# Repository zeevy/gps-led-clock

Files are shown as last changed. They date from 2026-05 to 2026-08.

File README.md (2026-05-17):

# GPS Clock with 32x8 LED Matrix Display

A sophisticated Arduino-based GPS clock that displays time on a 32x8 LED matrix with beautiful animations and effects. The clock automatically synchronizes with GPS time and includes a rain effect animation when GPS signal is lost.



## Features

- **GPS Time Synchronization**: Automatically syncs with GPS time (UTC) with timezone adjustment and signal quality monitoring
- **Dynamic Time Format**: Toggle between 12-hour (with AM/PM) or 24-hour display via power cycles
- **Animated Time Display**: Smooth vertical sliding animations when time digits change
- **Date Display**: Shows date with ordinal suffixes (1st, 2nd, 3rd, etc.) every 2 minutes 30 seconds
- **GPS Location Display**: Shows latitude, longitude, and altitude in feet (4 decimal places, ~11m accuracy) immediately after date display
- **Rain Effect Animation**: Beautiful rain animation when GPS signal is lost
- **Smart Signal Detection**: Uses GPS time age for reliable signal quality monitoring
- **Automatic Brightness Control**: Adjusts brightness based on time of day (night mode)
- **Fixed 32x8 Display**: Optimized for 4x MAX7219 LED matrix modules
- **Scrolling Text Messages**: Welcome and status messages with smooth scrolling
- **PM Indicator**: Visual indicator for PM time display
- **Blinking Colon**: Animated colon separator for time display

## Hardware Requirements

### Components

- **Arduino Nano** (or compatible Arduino board)
- **GPS Module** (NEO-6M or similar with NMEA output)
- **32x8 LED Matrix Display** (exactly 4x MAX7219 modules, 8x8 each)
- **Breadboard and jumper wires**
- **5V Power supply** (or USB power)

**Important**: This project is specifically designed for a **32x8 LED matrix** using **4x MAX7219 modules**. Other matrix sizes or configurations are not supported without code modifications.

**Note**: The matrix configuration is fixed and optimized for this specific setup. Changing the matrix size would require significant code modifications to the display logic, positioning calculations, and text scrolling functions.

### Pin Connections

| Component | Arduino Pin | Description |
|---|---|---|
| **GPS TX** | RX0 (Digital Pin 0)| GPS data output |
| **GPS VCC** | 5V | Power supply |
| **GPS GND** | GND | Ground |
| **LED Matrix DIN**  | Pin 11 (MOSI) | Data input |
| **LED Matrix CLK**  | Pin 13 (SCK) | Clock signal |
| **LED Matrix CS** | Pin 10 (SS) | Chip select |
| **LED Matrix VCC**  | 5V | Power supply |
| **LED Matrix GND**  | GND | Ground |



https://github.com/user-attachments/assets/0466696c-467c-4d51-b680-a392c1aeb819

## Software Requirements

- **PlatformIO** (recommended) or Arduino IDE
- **Arduino AVR Boards** package
- Required libraries (automatically installed with PlatformIO):
  - TinyGPSPlus
  - Adafruit GFX Library
  - Max72xxPanel
  - RTClib
  - TickTwo

## Installation & Setup

### Using PlatformIO (Recommended)

**Clone the repository**:

```bash
git clone https://github.com/zeevy/gps-led-clock.git
cd gps-led-clock
```

**Open in PlatformIO**:

```bash
pio project init
```

**Build and upload**:

```bash
pio run -t upload
```

> **Note:** Disconnect the GPS TX pin from Arduino RX0 during flashing/uploading.

## Configuration

### Time Format Configuration

The time format can be toggled dynamically using power cycle detection:

**Power Cycle Toggle:**

- **5 power cycles** during **startup sequence** toggles between formats
- Power cycles must occur between the random pixel animation and welcome message
- **12-hour format** is the default
- Format is stored in EEPROM and persists across reboots
- Format confirmation is shown when toggled

**12-Hour Format:**

- Displays time as 1:00 PM to 12:59 AM
- Shows PM indicator (bottom-right pixel) for PM times
- Example: "2:35." with PM indicator

**24-Hour Format:**

- Displays time as 00:00 to 23:59
- No AM/PM indicator
- Example: "14:35" (no indicator)

**How to Toggle:**

1. Power on the device
2. During the startup animation (between random pixel lighting and welcome message), power off the device and power it back on, repeating this 5 times
3. Wait for the welcome message to complete
4. If toggled, display will show the new format confirmation ("24H FORMAT" or "12H FORMAT")
5. New format persists across reboots

### Timezone Adjustment

To change the timezone, modify the timezone offset in `src/config.h`:

```cpp
// Current: IST (UTC+5:30)
#define TIMEZONE_OFFSET_DAYS    0
#define TIMEZONE_OFFSET_HOURS   5
#define TIMEZONE_OFFSET_MINUTES 30
#define TIMEZONE_OFFSET_SECONDS 0
```

### LED Matrix Configuration

This project is designed specifically for a **32x8 LED matrix** using **4x MAX7219 modules**. The matrix size and configuration are fixed and cannot be changed without code modifications.

**Matrix Specifications:**

- **Display Size**: 32x8 pixels
- **Modules**: 4x MAX7219 (8x8 each)
- **Arrangement**: Horizontal (4 modules side by side)
- **Orientation**: Standard left-to-right

### Display Settings

Modify these constants in `src/config.h`:

```cpp
// Brightness Settings (Adjustable)
#define LED_BRIGHTNESS_HIGH         10    // High brightness (0-15)
#define LED_BRIGHTNESS_LOW          5     // Low brightness (0-15)

// Timing Settings (Adjustable)
#define TIME_UPDATE_INTERVAL_MS     500  // GPS update interval
#define DATE_DISPLAY_INTERVAL_MS    (2 * 60 * 1000UL + 30 * 1000UL) // Date display interval
```

## Usage

### First Time Setup

1. **Power on** the device
2. **Wait for GPS signal** - Rain effect shows until GPS signal is acquired, every `DATE_DISPLAY_INTERVAL_MS` "Waiting for GPS signal..." will be shown, if GPS fix is not yet acquired
3. **Time will appear** once GPS signal is acquired

### Normal Operation

- **Time Display**: Shows current time in configurable format (12-hour or 24-hour) with blinking colon
- **Date Display**: Automatically shows date every 2 minutes 30 seconds
- **GPS Location**: Shows latitude, longitude, and altitude in feet (4 decimal places) after date display
- **PM Indicator**: Bottom-right pixel indicates PM time (12-hour format only)
- **Night Mode**: Automatically dims display from 9 PM to 6 AM
- **Rain Effect**: Activates when GPS signal is lost

### Serial Monitor

Connect to the serial monitor (115200 baud) to see:

- GPS data during signal acquisition
- Timestamp updates
- Status messages

## Customization

### Adding Custom Messages

Modify the welcome message in `src/config.h`:

```cpp
const char* WELCOME_MESSAGE = "Your Custom Message";
```

### Rain Effect Settings

Adjust rain effect parameters in `src/RainEffect.h`:

```cpp
static const int MAX_RAINDROPS = 12;           // Number of simultaneous drops
static const int RAIN_SPAWN_INTERVAL_MS = 200; // Spawn rate
static const int RAIN_FALL_SPEED_MIN_MS = 50;  // Minimum fall speed
static const int RAIN_FALL_SPEED_MAX_MS = 100; // Maximum fall speed
```

## Contributing

Contributions are welcome! Please feel free to submit a Pull Request. For major changes, please open an issue first to discuss what you would like to change.

### Development Guidelines

1. **Code Style**: Follow Arduino C++ conventions
2. **Documentation**: Add comprehensive comments and docstrings
3. **Testing**: Test on actual hardware before submitting
4. **Commits**: Use clear, descriptive commit messages

## Support

If you encounter any issues or have questions:

1. Search existing [Issues](https://github.com/zeevy/gps-led-clock/issues)
2. Create a new issue with detailed information
3. Include hardware setup and error messages

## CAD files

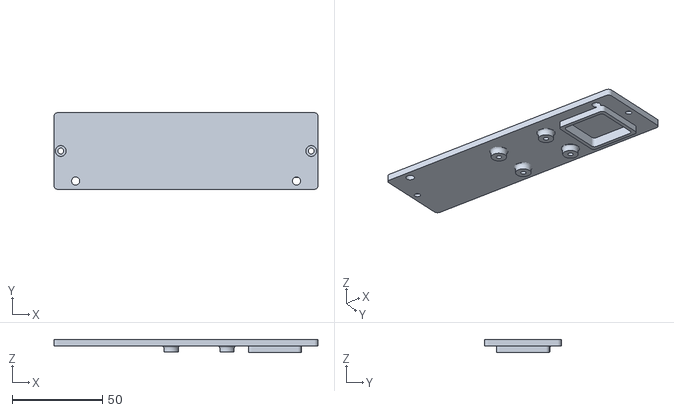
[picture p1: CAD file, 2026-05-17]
assets/back_panel.stl
146.5 x 42.5 x 6.95

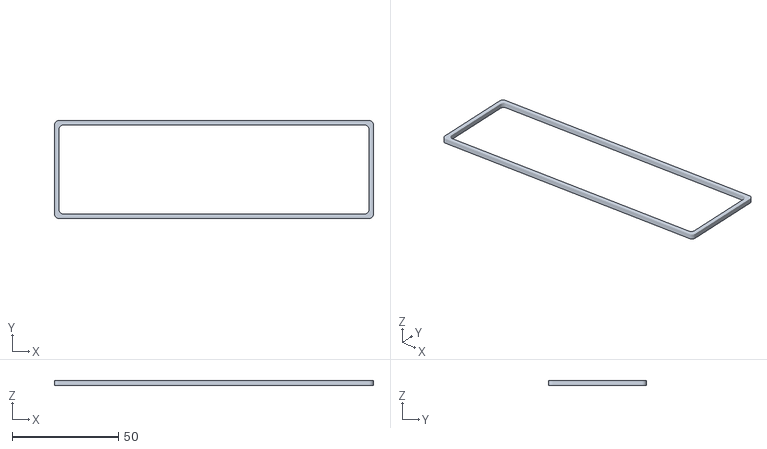
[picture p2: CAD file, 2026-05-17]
assets/ring.stl
150.0 x 46.0 x 2.40

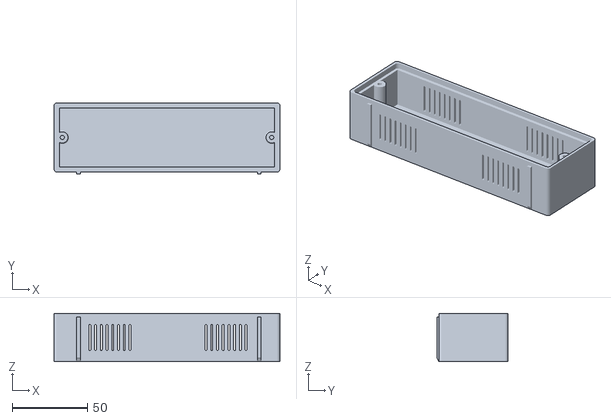
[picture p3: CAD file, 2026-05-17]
assets/case.stl
150.0 x 47.5 x 32.0

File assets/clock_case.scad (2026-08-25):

/*
 * Wall Clock Case for LED Matrix Display
 *
 * A 3D printable case designed for a 4x MAX7219 LED matrix display
 * with integrated GPS module mounting and ventilation system.
 *
 * Features:
 * - Customizable dimensions for different LED matrix sizes
 * - Integrated ventilation system for heat dissipation (optional cross-flow)
 * - GPS module mounting (Neo-6M compatible)
 * - M3 screw mounting system
 * - Rounded corners
 * - Modular design for easy customization
 *
 * Author: zeevy
 * License: MIT
 * Version: 1.1
 *
 * Dependencies:
 * - OpenSCAD 2019.05 or later
 *
 * Usage:
 * - Toggle the render flags in the Assembly section to choose what to export.
 * - Adjust parameters in the Configuration section as needed.
 * - Use $preview = true for fast preview, false for final render.
 */

// ============================================================================
// CONFIGURATION PARAMETERS
// ============================================================================

// Rendering quality
$fn = $preview ? 30 : 96;

// Render epsilon. Keeps boolean cuts from leaving zero-thickness faces.
// Tuned separately from physical assembly clearance (see back_panel_fit_tolerance).
eps = 0.05;

// Material and manufacturing parameters
wall_thickness        = 3.5;    // Thickness of case walls
screen_thickness      = 0.64;   // Thickness of screen/display area

// LED Matrix Display dimensions (MAX7219 4x configuration)
// Module is 128 x 33 x 15 mm (L x W x H) per the Handson Technology DSP-1172
// datasheet. Each dimension below is the module size plus a print clearance;
// the base numbers must stay equal to the datasheet, not to the 32 mm the
// matrix area alone measures, or the pocket ends up a press fit.
led_matrix_clearance_xy = 1.0;   // Clearance added to length and width
led_matrix_clearance_z  = 0.5;   // Clearance added to height
led_matrix_length     = 128 + led_matrix_clearance_xy;  // Module length + clearance
led_matrix_width      = 33  + led_matrix_clearance_xy;  // Module width + clearance
led_matrix_height     = 15  + led_matrix_clearance_z;   // Module height + clearance

// Main case dimensions
case_length           = 150;    // Total length of the case
case_width            = 46;     // Total width of the case
case_height           = 32;     // Total height of the case
case_bottom_thickness = 5;      // Thickness of bottom panel that holds the LED matrix
case_corner_radius    = 2;      // Corner radius for case and panel geometry

// Back panel fit. Total radial clearance between panel and its recess in the case.
back_panel_fit_tolerance = 0.3;

// Ventilation
ventilation_hole_diameter   = 1.26;
ventilation_slot_length     = 16;
ventilation_hole_spacing    = 3.8;
ventilation_hole_count      = 8;
ventilation_enable_back_wall = true;  // Mirror vents to opposite long wall for cross-flow

// GPS antenna (Neo-6M is square ~25mm)
gps_antenna_size            = 25.25;
gps_module_cutout_inset_x   = 40;   // Distance from case end (back panel antenna cutout)
gps_module_bracket_inset_x  = 42;   // Distance from case end (back panel bracket)
gps_post_origin_x           = 96;   // X offset for Neo-6M PCB mounting posts (back panel frame)
gps_post_spacing_x          = 31;   // PCB hole spacing in X (Neo-6M board)
gps_post_spacing_y          = 20.6; // PCB hole spacing in Y (Neo-6M board)

// Hardware
m3_screw_tap_hole_diameter         = 2.8;   // Self-tap hole in mounting feet
m3_screw_shaft_clearance_diameter  = 3.25;  // Through-hole in back panel
m3_screw_distance_from_edge        = 5.5;   // Distance from case edge to mounting feet/holes
m3_screw_head_recess_diameter      = 6;     // Counterbore diameter for screw head
// Counterbore depth into the back panel. With 2.0mm depth in a 3.5mm panel, a
// standard 3mm cap head will sit ~1mm proud. Increase toward ~3.0mm if you use
// flat/countersunk M3 screws (panel still needs material below the recess).
m3_screw_head_recess_depth         = 2;

// Cable management
cable_pass_through_diameter        = 4.5;
cable_pass_through_inset_x         = 12;  // Distance from each end of the back panel
cable_pass_through_y               = 4.6;

// Mounting bars on the underside of the case
foot_bar_inset_x                   = 15;

// Display ring
display_ring_thickness             = 2.4;  // Z thickness of the ring
display_ring_border                = 4.2;  // XY width of the ring border

// Assembly render toggles
render_case        = false;
render_back_panel  = false;
render_display_ring = true;

// ============================================================================
// SANITY ASSERTIONS
// ============================================================================

assert(case_length > led_matrix_length + 2 * wall_thickness,
       "case_length must accommodate led_matrix_length plus side walls");
assert(case_width > led_matrix_width + 2 * wall_thickness,
       "case_width must accommodate led_matrix_width plus side walls");
assert(case_height > led_matrix_height + case_bottom_thickness + wall_thickness,
       "case_height must accommodate led_matrix_height plus floor and back panel");
assert(m3_screw_head_recess_depth < wall_thickness,
       "m3_screw_head_recess_depth must leave material below; reduce depth or thicken wall");

// ============================================================================
// MAIN ASSEMBLY
// ============================================================================

color("lightgray") {
  if (render_case) {
    led_case();
  }

  if (render_back_panel) {
    translate([
      wall_thickness/2,
      wall_thickness/2,
      case_height - wall_thickness + display_ring_thickness/2
    ]) led_case_back_panel(include_holes = true, gap = 0);
  }

  if (render_display_ring) {
    translate([0, 0, display_ring_thickness/2]) display_ring();
  }
}

// ============================================================================
// CORE MODULES
// ============================================================================

/**
 * Main LED case. Primary housing for the LED matrix display with integrated
 * ventilation, mounting points, and cable management.
 */
module led_case() {
  union() {
    difference() {
      // Outer case shell
      rounded_box(case_length, case_width, case_height, case_corner_radius);

      // Interior cavity
      translate([wall_thickness, wall_thickness, case_bottom_thickness]) {
        cube([case_length - wall_thickness * 2,
              case_width - wall_thickness * 2,
              case_height + wall_thickness]);
      }

      // LED matrix cutout
      translate([(case_length - led_matrix_length)/2,
                 (case_width - led_matrix_width)/2,
                 screen_thickness]) {
        led_matrix_cutout();
      }

      // Back panel mounting recess. Subtract ONLY the plate shape so the GPS
      // bracket and mounting posts (added by led_case_back_panel) do not also
      // carve features into the case body.
      translate([wall_thickness/2,
                 wall_thickness/2,
                 case_height - wall_thickness + eps]) {
        back_panel_plate(include_holes = false, gap = back_panel_fit_tolerance);
      }

      // Ventilation on the y=0 long wall
      create_ventilation_slots(start_x = 20);
      create_ventilation_slots(
        start_x = case_length - (20 + ventilation_hole_spacing * ventilation_hole_count + ventilation_hole_diameter * 2)
      );

      // Optional mirrored vents on the y=case_width wall for cross-flow
      if (ventilation_enable_back_wall) {
        translate([0, case_width, 0]) mirror([0, 1, 0]) {
          create_ventilation_slots(start_x = 20);
          create_ventilation_slots(
            start_x = case_length - (20 + ventilation_hole_spacing * ventilation_hole_count + ventilation_hole_diameter * 2)
          );
        }
      }
    }

    create_mounting_feet();
    create_bottom_feet();
  }
}

/**
 * Back panel assembly: plate plus GPS bracket plus GPS PCB mounting posts.
 * @param include_holes Whether to include screw, GPS, and cable cutouts.
 * @param gap Additional clearance applied to the plate footprint.
 */
module led_case_back_panel(include_holes = true, gap = 0) {
  union() {
    back_panel_plate(include_holes, gap);
    create_gps_mounting_bracket();
    translate([gps_post_origin_x, case_width/4, eps * 2]) {
      rotate([0, 180, 0]) neo_6m_mounting_posts();
    }
  }
}

/**
 * Back panel plate only (rounded box plus optional cutouts). Used standalone
 * for the printed plate and as the recess shape carved into the case body.
 */
module back_panel_plate(include_holes = true, gap = 0) {
  difference() {
    rounded_box(
      case_length - wall_thickness + gap,
      case_width  - wall_thickness + gap,
      wall_thickness,
      case_corner_radius
    );
    if (include_holes) {
      create_m3_mounting_holes();
      create_gps_module_cutout();
      create_cable_pass_throughs();
    }
  }
}
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

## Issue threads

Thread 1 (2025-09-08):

Replace single fixed EEPROM addresses with a slot-based wear-leveling system.

zeevy, 2025-09-08:
The Arduino project currently stores user settings (like 12h/24h mode) and counters (like power-cycle count) in EEPROM at fixed addresses.
Since EEPROM cells have a limited write endurance (~100k cycles per cell), repeatedly writing to the same address can eventually wear it out.

We want to extend the lifetime by implementing a simple wear-leveling mechanism: instead of always writing to the same EEPROM address, distribute writes across a predefined set of slots (e.g., 16).

Have a dedicated file/class for this

Replace single fixed EEPROM addresses with a slot-based wear-leveling system.
Add logic to rotate writes across slots and scan for the latest value at startup.
Keep defaults and validation in place so the system is robust.

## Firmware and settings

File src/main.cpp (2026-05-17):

/**
 * @file main.cpp
 * @brief GPS Clock with 4xMAX7219 LED Matrix Display
 * 
 * This Arduino project creates a GPS-synchronized clock that displays time on a 32x8 LED matrix.
 * The project is specifically designed for 4x MAX7219 modules arranged horizontally.
 * Features include:
 * - GPS time synchronization with timezone adjustment
 * - Animated time display with vertical slide transitions
 * - Date display with ordinal suffixes
 * - Rain effect animation when GPS signal is lost
 * - Automatic brightness adjustment for day/night
 * - Scrolling text messages
 * - Fixed 32x8 matrix display (4x MAX7219 modules)
 * 
 * @author zeevy
 * @version 1.0.0
 * @date 2025-09-06
 * @license MIT
 */

#include <config.h>
#include "RainEffect.h"
#include "GpsStabilityFilter.h"

// ============================================================================
// CONSTANTS AND CONFIGURATION
// ============================================================================

// Space between characters in pixels for text scrolling
const int CHAR_SPACING = 1;

// Total character width including spacing for text scrolling
const int CHAR_WIDTH = 5 + CHAR_SPACING;

// ============================================================================
// GLOBAL VARIABLES
// ============================================================================

// ----------------------------------------------------------------------------
// GPS AND SIGNAL TRACKING
// ----------------------------------------------------------------------------
TinyGPSPlus gpsModule;                    // GPS module interface
bool wasShowingRainEffect = false;        // Track previous rain effect state for efficient screen clearing
GpsStabilityFilter gpsFilter(gpsModule);  // GPS coordinates stability filter

// ----------------------------------------------------------------------------
// TIME AND DATE MANAGEMENT
// ----------------------------------------------------------------------------
DateTime currentDateTime;                 // Current date and time from GPS
TimeDigits currentTimeDigits;             // Current time digits for display
TimeDigits previousTimeDigits;            // Previous time digits for animation comparison
bool is24Hour = false;                    // Time format cache (read once in setup for performance)
bool toggleBlinker = false;               // Controls colon blinking state in time display

// ----------------------------------------------------------------------------
// DISPLAY AND ANIMATION
// ----------------------------------------------------------------------------
Max72xxPanel ledMatrix = Max72xxPanel(MATRIX_CS_PIN, MATRIX_TOTAL_MODULES_X, MATRIX_TOTAL_MODULES_Y);
RainEffect rainEffect(ledMatrix);         // Rain effect animation object
char textScrollBuffer[TEXT_BUFFER_SIZE];  // Buffer for scrolling text display

// ----------------------------------------------------------------------------
// TIMERS
// ----------------------------------------------------------------------------
TickTwo gpsTimeUpdateTicker(updateGpsTime, TIME_UPDATE_INTERVAL_MS);  // Timer for GPS time updates
TickTwo dateDisplayTicker(displayDate, DATE_DISPLAY_INTERVAL_MS);     // Timer for date display

/**
 * @brief Arduino setup function - initializes the GPS clock system
 * 
 * This function performs the following initialization steps:
 * 1. Initializes serial communication for debugging
 * 2. Configures the LED matrix display
 * 3. Runs a startup animation
 * 4. Displays welcome message
 * 5. Starts the GPS time update and date display timers
 * 
 * @note This function runs once when the Arduino starts up
 */
void setup() {
  Serial.begin(115200);
  while (!Serial) delay(100);

  // Initialize LED matrix with low brightness
  ledMatrix.setIntensity(LED_BRIGHTNESS_LOW);
  ledMatrix.fillScreen(LOW);
  ledMatrix.write();
  configureLedMatrix();

  // Read time format from EEPROM once
  uint8_t format = EEPROM.read(EEPROM_TIME_FORMAT_ADDR);
  is24Hour = (format == 1);

  // Detect power cycles for time format switching
  checkPowerCycles();

  // Fun startup animation: randomly light up LEDs (increased delay for power cycle detection)
  randomSeed(analogRead(A0));
  for (int i = 0; i < ledMatrix.width() * ledMatrix.height(); i++) {
    ledMatrix.drawPixel(random(ledMatrix.width()), random(ledMatrix.height()), HIGH);
    ledMatrix.write();
    delay(5);
  }

  // Display welcome message and start timers
  scrollTextHorizontally(WELCOME_MESSAGE);

  // Reset power cycle counter after welcome message
  EEPROM.put(EEPROM_POWER_CYCLE_ADDR, (unsigned long)0);

  gpsTimeUpdateTicker.start();
  dateDisplayTicker.start();
}

void loop() {
  while (Serial.available()){
    char receivedChar = Serial.read();
    gpsModule.encode(receivedChar);
  }

  if (validGpsDateTime()) {
    // GPS signal good - clear screen if transitioning from rain effect
    // This prevents rain drops from being visible with time display
    if (wasShowingRainEffect) {
      ledMatrix.fillScreen(LOW);
      rainEffect.reset();
      previousTimeDigits = TimeDigits();
      wasShowingRainEffect = false;
    }

    gpsTimeUpdateTicker.update();
    dateDisplayTicker.update();
  }else{
    // GPS signal lost - show rain effect
    if (!rainEffect.isInitialized()) rainEffect.initialize();
    rainEffect.update();
    rainEffect.render();
    wasShowingRainEffect = true;
  }
}

/**
 * @brief Checks if the GPS date and time are valid and recent.
 * 
 * This function validates that the GPS location, date, and time are all valid,
 * and that the GPS data is not stale (i.e., received within the configured timeout).
 * 
 * @return true if GPS location, date, and time are valid and recent; false otherwise.
 */
bool validGpsDateTime() {
  return gpsModule.location.isValid() &&
         gpsModule.location.age() < GPS_SIGNAL_TIMEOUT_MS &&
         gpsModule.date.isValid() &&
         gpsModule.time.isValid();
}

/**
 * @brief Updates GPS time and displays it on the LED matrix
 * 
 * This function is called periodically by the GPS time update timer. It:
 * 1. Validates GPS data availability
 * 2. Converts GPS time to local timezone (configurable)
 * 3. Extracts individual time digits
 * 4. Animates digit changes with vertical slide effect
 * 5. Displays PM indicator and blinking colon
 * 
 * @note This function is called every TIME_UPDATE_INTERVAL_MS milliseconds
 * @note Timezone offset is configurable in config.h via TIMEZONE_OFFSET_* defines
 */
void updateGpsTime() {
  if (gpsModule.date.isValid() && gpsModule.time.isValid()) {
    // Create DateTime object from GPS data with timezone adjustment
    // Timezone offset is configured in config.h
    currentDateTime = DateTime(
      gpsModule.date.year(), gpsModule.date.month(), gpsModule.date.day(),
      gpsModule.time.hour(), gpsModule.time.minute(), gpsModule.time.second()
    ) + TimeSpan(TIMEZONE_OFFSET_DAYS, TIMEZONE_OFFSET_HOURS, TIMEZONE_OFFSET_MINUTES, TIMEZONE_OFFSET_SECONDS);

    // Extract individual digits for display
    extractTimeDigits(currentTimeDigits);

    // Animate digit changes with vertical slide effect
    if (currentTimeDigits.minOnes != previousTimeDigits.minOnes) {
      animateVerticalSlide(previousTimeDigits.minOnes, currentTimeDigits.minOnes, 25);
    }

    if (currentTimeDigits.minTens != previousTimeDigits.minTens) {
      animateVerticalSlide(previousTimeDigits.minTens, currentTimeDigits.minTens, 18);
    }

    if (currentTimeDigits.hourOnes != previousTimeDigits.hourOnes) {
      animateVerticalSlide(previousTimeDigits.hourOnes, currentTimeDigits.hourOnes, 7);
    }

    if (currentTimeDigits.hourTens != previousTimeDigits.hourTens) {
      animateVerticalSlide(previousTimeDigits.hourTens, currentTimeDigits.hourTens, 1);
    }

    // Display PM indicator in bottom-right corner (only in 12-hour format)
    if (!is24Hour) {
      ledMatrix.drawPixel(ledMatrix.width() - 1, ledMatrix.height() - 1, currentDateTime.isPM());
    }

    // Toggle the colon blinker for time separator
    for (byte i = 0; i < sizeof(COLON_BLINK_POSITIONS) / sizeof(COLON_BLINK_POSITIONS[0]); i++) {
      ledMatrix.drawPixel(COLON_BLINK_POSITIONS[i][0], COLON_BLINK_POSITIONS[i][1], toggleBlinker);
    }

    ledMatrix.write();

    // Print timestamp to serial when seconds change (debug only)
    #if ENABLE_SERIAL_DEBUG
    if (currentTimeDigits.secOnes != previousTimeDigits.secOnes) {
      Serial.println(currentDateTime.timestamp(DateTime::TIMESTAMP_FULL));
    }
    #endif

    // Update previous digits for next comparison
    extractTimeDigits(previousTimeDigits);
    toggleBlinker = !toggleBlinker;
  }
}

/**
 * @brief Configures LED matrix module positions and rotations
 * 
 * This function sets up the 4x MAX7219 LED matrix modules for a 32x8 display.
 * The matrix is configured in a standard horizontal arrangement:
 * - 4 modules arranged horizontally (8x8 each)
 * - Total display size: 32x8 pixels
 * - Standard left-to-right positioning
 * - No rotation applied (0 degrees)
 * 
 * @note This function is designed specifically for 4x MAX7219 modules
 * @note Matrix size is fixed to 32x8 pixels
 */
void configureLedMatrix() {
  int totalModules = MATRIX_TOTAL_MODULES_X * MATRIX_TOTAL_MODULES_Y;

  for (int moduleIndex = 0; moduleIndex < totalModules; moduleIndex++) {
    // Calculate base position for this module
    byte xPosition = moduleIndex % MATRIX_TOTAL_MODULES_X;
    byte yPosition = moduleIndex / MATRIX_TOTAL_MODULES_X;
    byte rotationAngle = 1; // Default rotation (0 degrees)

    ledMatrix.setPosition(moduleIndex, xPosition, yPosition);
    ledMatrix.setRotation(moduleIndex, rotationAngle);
  }
}

/**
 * @brief Scrolls text horizontally across the LED matrix display
 * 
 * This function creates a smooth horizontal scrolling effect for text messages.
 * The text scrolls from right to left across the display. If the text is shorter
 * than the display width, it will still scroll to ensure visibility.
 * 
 * @param message The text message to scroll (null-terminated string)
 * 
 * @note The function adds a space at the end of the message for better readability
 * @note Scroll speed is controlled by the delay(30) - adjust for different speeds
 * @note This function resets the previousTimeDigits to prevent animation conflicts
 * 
 * @example
 * scrollTextHorizontally("Hello World"); // Scrolls "Hello World " across display
 */
void scrollTextHorizontally(const char* message) {  
  // Print message to serial for debugging
  #if ENABLE_SERIAL_DEBUG
  Serial.println(message);
  #endif

  // Prepare text buffer with trailing space for better readability
  snprintf(textScrollBuffer, sizeof(textScrollBuffer), "%s ", message);

  // Calculate total text width in pixels
  int totalTextWidth = strlen(textScrollBuffer) * CHAR_WIDTH;
  
  // Ensure minimum scroll distance is at least the display width
  if (totalTextWidth < ledMatrix.width()) {
    totalTextWidth = ledMatrix.width();
  }

  // Scroll text from right edge to left edge
  for (int xPosition = ledMatrix.width(); xPosition >= -totalTextWidth; xPosition--) {
    // Drain serial buffer to prevent GPS data loss during long scrolls
    while (Serial.available()) {
      gpsModule.encode(Serial.read());
    }

    // Clear display and set cursor position
    ledMatrix.fillScreen(LOW);
    ledMatrix.setCursor(xPosition, 0);
    ledMatrix.print(textScrollBuffer);
    ledMatrix.write();
    delay(35); // Control scroll speed (35ms per frame)
  }

  // Reset previous time digits to prevent animation conflicts
  previousTimeDigits = TimeDigits();
}

/**
 * @brief Displays the current date with ordinal suffixes and adjusts brightness
 * 
 * This function is called periodically by the date display timer. It:
 * 1. Checks if GPS time is acquired, shows waiting message if not
 * 2. Formats the date with weekday, day with ordinal suffix, month, and year
 * 3. Scrolls the formatted date across the display
 * 4. Adjusts LED brightness based on time of day (night mode)
 * 
 * @note Called every DATE_DISPLAY_INTERVAL_MS milliseconds
 * @note Night mode: low brightness from 9PM to 6AM, high brightness otherwise
 * @note Date format: "Mon 1st Jan 2024" (example)
 * 
 * @example
 * // If current date is Monday, January 1st, 2024
 * // Display will show: "Mon 1st Jan 2024"
 */
void displayDate() {
  // Show waiting message if GPS time is not valid
  if (!gpsModule.time.isValid()) {
    scrollTextHorizontally(WAITING_FOR_GPS);
    return;
  }

  // Bounds checking for array access using Arduino constrain function
  int dayOfWeek = constrain(currentDateTime.dayOfTheWeek(), 0, 6);
  int month = constrain(currentDateTime.month(), 1, 12);

  // Format date string with ordinal suffix
  // Format: "Day OrdinalSuffix Month Year" (e.g., "Mon 1st Jan 2024")
  int day = currentDateTime.day();
  const char* ordinalSuffix = getOrdinalSuffix(day);

  snprintf(
    textScrollBuffer, sizeof(textScrollBuffer),
    "%s %d%s %s %d",
    WEEKDAY_NAMES[dayOfWeek],
    day,
    ordinalSuffix,
    MONTH_NAMES[month - 1],
    currentDateTime.year()
  );

  // Display the formatted date
  scrollTextHorizontally(textScrollBuffer);
  displayGpsLocation();

  // Adjust brightness based on time of day (night mode)
  if (currentDateTime.hour() >= 21 || currentDateTime.hour() <= 6) {
    // Night hours: 9PM to 6AM - use low brightness
    ledMatrix.setIntensity(LED_BRIGHTNESS_LOW);
  } else {
    // Day hours: 6AM to 9PM - use high brightness
    ledMatrix.setIntensity(LED_BRIGHTNESS_HIGH);
  }
}

/**
 * @brief Returns the appropriate ordinal suffix for a given number
 * 
 * This function determines the correct ordinal suffix (st, nd, rd, th) for a number.
 * It handles special cases for numbers ending in 11, 12, 13 (which all use "th")
 * and regular cases for other numbers.
 * 
 * @param number The number to get the ordinal suffix for
 * @return Pointer to the ordinal suffix string ("st", "nd", "rd", or "th")
 * 
 * @note This is a helper function for date formatting
 * 
 * @example
 * getOrdinalSuffix(1)  // Returns "st" (1st)
 * getOrdinalSuffix(2)  // Returns "nd" (2nd)
 * getOrdinalSuffix(3)  // Returns "rd" (3rd)
 * getOrdinalSuffix(11) // Returns "th" (11th)
 * getOrdinalSuffix(21) // Returns "st" (21st)
 */
const char* getOrdinalSuffix(int number) {
  int lastTwoDigits = number % 100;
  int lastDigit = number % 10;

  // Special case: 11th, 12th, 13th all use "th"
  if (lastTwoDigits >= 11 && lastTwoDigits <= 13) {
    return "th";
  } else {
    // Regular cases based on last digit
    switch (lastDigit) {
      case 1: return "st";
      case 2: return "nd";
      case 3: return "rd";
      default: return "th";
    }
  }
}

/**
 * @brief Extracts individual digits from the current time for display
 * 
 * This function takes the current date/time and extracts individual digits
 * for hours, minutes, and seconds. It converts the numeric values to ASCII
 * characters for display on the LED matrix.
 * 
 * @param digits Reference to TimeDigits struct to store the extracted digits
 * 
 * @note Uses configurable time format (12-hour or 24-hour) based on TIME_FORMAT_* defines
 * @note All digits are converted to ASCII characters ('0' to '9')
 * 
 * @example
 * // 12-hour format: If current time is 2:35:47 PM
 * // digits.hourTens = '0', digits.hourOnes = '2'
 * // 24-hour format: If current time is 14:35:47
 * // digits.hourTens = '1', digits.hourOnes = '4'
 */
void extractTimeDigits(TimeDigits& digits) {
  // Get time components based on cached format
  int hour;
  if (is24Hour) {
    hour = currentDateTime.hour();
  } else {
    hour = currentDateTime.twelveHour();
  }

  int minute = currentDateTime.minute();
  int second = currentDateTime.second();

  // Extract and convert digits to ASCII characters
  digits.hourOnes = (hour % 10) + '0';
  digits.hourTens = (hour / 10) + '0';
  digits.minOnes = (minute % 10) + '0';
  digits.minTens = (minute / 10) + '0';
  digits.secOnes = (second % 10) + '0';
  digits.secTens = (second / 10) + '0';
}

/**
 * @brief Creates a vertical sliding animation when time digits change
 * 
 * This function creates a smooth vertical sliding effect when a time digit changes.
 * The old character slides down while the new character slides up from the top,
 * creating a visually appealing transition effect.
 * 
 * @param previousChar The character that was previously displayed
 * @param newChar The new character to display
 * @param xPosition The X coordinate where the animation occurs
 * 
 * @note Animation speed is controlled by delay(25) - adjust for different speeds
 * @note This function blocks execution during animation
 * 
 * @example
 * animateVerticalSlide('5', '6', 25); // Animate change from '5' to '6' at x=25
 */
void animateVerticalSlide(char previousChar, char newChar, int xPosition) {
  // Create sliding effect by moving both characters vertically
  for (uint8_t yPosition = 0; yPosition <= ledMatrix.height(); yPosition++) {
    // Draw new character sliding up from top
    ledMatrix.drawChar(xPosition, yPosition - ledMatrix.height(), newChar, HIGH, LOW, 1);
    // Draw previous character sliding down
    ledMatrix.drawChar(xPosition, yPosition, previousChar, HIGH, LOW, 1);
    ledMatrix.write();
    delay(25); // Control animation speed (25ms per frame)
  }
}

/**
 * @brief Displays GPS location information (latitude, longitude, altitude)
 * 
 * This function displays the current GPS coordinates
 * immediately after the date display. It shows:
 * - Latitude with "LAT:" prefix (4 decimal places, ~11m accuracy)
 * - Longitude with "LON:" prefix (4 decimal places, ~11m accuracy)
 * - Altitude with "ALT:" prefix and "ft" suffix (1 decimal place,
 * 
 * @note Only displays if GPS location data is valid
 * @note Each coordinate is displayed on a separate line with scrolling
 * @note GPS precision is fixed at 4 decimal places for optimal readability
 * @note All values are validated before display to prevent invalid data
 * @note Uses integer arithmetic to avoid sprintf floating-point issues on Arduino
 */
void displayGpsLocation() {
  if (!gpsModule.location.isValid()) return;

  // Update GPS stability filter with new readings
  gpsFilter.update();

  // Display latitude using filtered value for stability (4 decimal places = ~11m accuracy)
  float lat = gpsFilter.getFilteredLatitude();
  int latInt = (int)lat;
  int latFrac = (int)(fabs(lat - latInt) * GPS_COORD_PRECISION_MULTIPLIER);

  #if ENABLE_SERIAL_DEBUG
  // Debug output: show raw vs filtered values
  Serial.print("LAT - Raw: ");
  Serial.print(gpsModule.location.lat(), 6);
  Serial.print(", Filtered: ");
  Serial.print(lat, 6);
  Serial.print(", Readings: ");
  Serial.println(gpsFilter.getTotalReadings());
  #endif

  snprintf(textScrollBuffer, sizeof(textScrollBuffer), "%s%d.%04d", GPS_LAT_PREFIX, latInt, latFrac);
  scrollTextHorizontally(textScrollBuffer);

  // Display longitude using filtered value for stability (4 decimal places = ~11m accuracy)
  float lng = gpsFilter.getFilteredLongitude();
  int lngInt = (int)lng;
  int lngFrac = (int)(fabs(lng - lngInt) * GPS_COORD_PRECISION_MULTIPLIER);

  #if ENABLE_SERIAL_DEBUG
  // Debug output: show raw vs filtered values
  Serial.print("LON - Raw: ");
  Serial.print(gpsModule.location.lng(), 6);
  Serial.print(", Filtered: ");
  Serial.println(lng, 6);
  #endif

  snprintf(textScrollBuffer, sizeof(textScrollBuffer), "%s%d.%04d", GPS_LON_PREFIX, lngInt, lngFrac);
  scrollTextHorizontally(textScrollBuffer);

  // Display altitude using filtered value for stability if available
  if (gpsModule.altitude.isValid()) {
    // Use filtered altitude value and integer arithmetic since Arduino sprintf doesn't support floating-point
    double altFeet = gpsFilter.getFilteredAltitude();
    int altInt = (int)altFeet;
    int altFrac = (int)(fabs(altFeet - altInt) * GPS_ALT_PRECISION_MULTIPLIER);

    #if ENABLE_SERIAL_DEBUG
    // Debug output: show raw vs filtered altitude
    Serial.print("ALT - Raw: ");
    Serial.print(gpsModule.altitude.feet(), 2);
    Serial.print("ft, Filtered: ");
    Serial.print(altFeet, 2);
    Serial.println("ft");
    #endif

    snprintf(textScrollBuffer, sizeof(textScrollBuffer), "%s%d.%d%s", GPS_ALT_PREFIX, altInt, altFrac, GPS_ALT_SUFFIX);
    scrollTextHorizontally(textScrollBuffer);
  }
}

/**
 * @brief Detects power cycles and toggles time format if threshold is reached
 * 
 * This function detects power cycles during the startup sequence to toggle between 
 * 12-hour and 24-hour time formats. The detection uses EEPROM to store cycle count.
 * 
 * The system works by incrementing a counter on each power cycle during startup.
 * If the counter reaches the threshold (5), it toggles the time format and resets 
 * the counter. The counter is reset after the welcome message to prevent accidental 
 * toggles during normal operation.
 * 
 * @note Called in setup() to detect power cycles for format switching
 * @note Uses EEPROM to persist cycle data across reboots
 * @note Counter resets after welcome message
 */
void checkPowerCycles() {
  // Read cycle count from EEPROM
  unsigned long cycleCount = 0;
  EEPROM.get(EEPROM_POWER_CYCLE_ADDR, cycleCount);

  // Validate against uninitialized EEPROM (0xFFFFFFFF) or corrupt values
  if (cycleCount > POWER_CYCLE_THRESHOLD * 2) {
    cycleCount = 0;
  }

  // Increment cycle count
  cycleCount++;
  EEPROM.put(EEPROM_POWER_CYCLE_ADDR, cycleCount);

  // If threshold reached, toggle time format
  if (cycleCount > POWER_CYCLE_THRESHOLD) toggleTimeFormat();
}
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

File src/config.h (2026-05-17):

/**
 * @file config.h
 * @brief Configuration header for GPS Clock with 32x8 LED Matrix Display
 * 
 * This file contains all configuration constants, pin definitions, and hardware
 * setup information for the GPS clock project. It includes LED matrix display
 * settings (fixed to 32x8), timing intervals, timezone configuration, and message definitions.
 * 
 * @author zeevy
 * @version 1.0.0
 * @date 2025-09-06
 * @license MIT
 */

#ifndef CONFIG_H
#define CONFIG_H

// ============================================================================
// LIBRARY INCLUDES
// ============================================================================

#include <Arduino.h>
#include <TinyGPS++.h>
#include <TickTwo.h>
#include <Adafruit_GFX.h>
#include <Max72xxPanel.h>
#include <RTClib.h>
#include <TimerOne.h>
#include <EEPROM.h>

// ============================================================================
// HARDWARE CONFIGURATION
// ============================================================================

/**
 * @brief Hardware pin connections for the GPS Clock
 * 
 * GPS Module Connections:
 * - GPS RX: Not connected (GPS module only transmits)
 * - GPS TX: Connected to Arduino RX0 (Digital Pin 0)
 * 
 * LED Matrix Connections (4xMAX7219):
 * - DIN (Data In): Connected to Arduino Pin 11 (MOSI)
 * - CLK (Clock): Connected to Arduino Pin 13 (SCK)
 * - CS (Chip Select): Connected to Arduino Pin 10 (SS)
 * - VCC: Connected to 5V
 * - GND: Connected to Ground
 */

// Pin Definitions
#define MATRIX_CS_PIN               10   // LED matrix chip select (CS) pin for SPI

// LED Matrix Display Configuration
// This project is designed specifically for a 32x8 LED matrix using 4x MAX7219 modules
// Matrix size is fixed and cannot be changed without code modifications
#define MATRIX_TOTAL_MODULES_X      4    // Number of LED matrix modules horizontally
#define MATRIX_TOTAL_MODULES_Y      1    // Number of LED matrix modules vertically

// LED Matrix Brightness Levels
static const int LED_BRIGHTNESS_HIGH       = 10;  // High brightness level (0-15), used during day time
static const int LED_BRIGHTNESS_LOW        = 5;  // Low brightness level (0-15), used during night time

// ============================================================================
// TIMING CONFIGURATION
// ============================================================================

// Update Intervals
#define TIME_UPDATE_INTERVAL_MS     500  // Interval to check for GPS time updates (also affects seconds blinker)
#define DATE_DISPLAY_INTERVAL_MS    (2 * 60 * 1000UL + 30 * 1000UL)  // Interval to display date (2 minutes 30 seconds)

// GPS Signal Management
const unsigned long GPS_SIGNAL_TIMEOUT_MS = 30000UL;  // GPS signal timeout (30 seconds) - rain effect shown if exceeded

// Colon Blink Positions for Time Separator (x, y coordinates)
static const byte COLON_BLINK_POSITIONS[][2] = {
  {14, 3}, {15, 3},  // Top row of colon
  {14, 4}, {15, 4}   // Bottom row of colon
};

// ============================================================================
// TIMEZONE CONFIGURATION
// ============================================================================

/**
 * @brief Timezone offset configuration
 * 
 * Adjust these values to set your local timezone offset from UTC.
 * The TimeSpan constructor takes: (days, hours, minutes, seconds)
 * 
 * Common timezone examples:
 * - IST (UTC+5:30): DAYS=0, HOURS=5,  MINUTES=30, SECONDS=0
 * - EST (UTC-5:00): DAYS=0, HOURS=-5, MINUTES=0,  SECONDS=0
 * - PST (UTC-8:00): DAYS=0, HOURS=-8, MINUTES=0,  SECONDS=0
 * - GMT (UTC+0:00): DAYS=0, HOURS=0,  MINUTES=0,  SECONDS=0
 * - JST (UTC+9:00): DAYS=0, HOURS=9,  MINUTES=0,  SECONDS=0
 * - CET (UTC+1:00): DAYS=0, HOURS=1,  MINUTES=0,  SECONDS=0
 * - AEST(UTC+10:00):DAYS=0, HOURS=10, MINUTES=0,  SECONDS=0
 * 
 * Note: Use negative values for timezones west of UTC
 */
#define TIMEZONE_OFFSET_DAYS    0    // Days offset from UTC
#define TIMEZONE_OFFSET_HOURS   5    // Hours offset from UTC (positive for east, negative for west)
#define TIMEZONE_OFFSET_MINUTES 30   // Minutes offset from UTC
#define TIMEZONE_OFFSET_SECONDS 0    // Seconds offset from UTC

// ============================================================================
// GPS DISPLAY CONFIGURATION
// ============================================================================

// GPS Location Display Messages
static const char* GPS_LAT_PREFIX          = "LAT:";  // Latitude prefix
static const char* GPS_LON_PREFIX          = "LON:";  // Longitude prefix
static const char* GPS_ALT_PREFIX          = "ALT:";  // Altitude prefix
static const char* GPS_ALT_SUFFIX          = "ft";    // Altitude suffix (feet)

// GPS Coordinate Precision Constants
#define GPS_COORD_PRECISION_MULTIPLIER  10000    // For 4 decimal places (~11m accuracy)
#define GPS_ALT_PRECISION_MULTIPLIER    10       // For 1 decimal place
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

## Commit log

2025-09-06 Initial commit: GPS Clock with 32x8 LED Matrix Display
2025-09-08 Add comprehensive copilot-instructions.md for GPS LED clock project
2025-09-20 - Improved rain effect - STL files added for 3D printing
    [display_ring.stl, led_case.stl, led_case_back_panel.stl]
2025-09-23 Implement GPS coordinates stability filtering system
    [config.h, main.cpp]
2025-09-23 Fix edge cases in GPS filtering and add comprehensive validation
    [main.cpp]
2025-09-23 Refactor GPS stability filtering into separate class like RainEffect
    [config.h, main.cpp]
2025-09-24 GPS Lat, Lon, Alt stability filter added
2026-05-17 Firmware bug fixes and EEPROM robustness (#10)
    - config.h: add static qualifier to all variable definitions in the
    header. Without it, including config.h from main.cpp, RainEffect.cpp,
    and GpsStabilityFilter.cpp creates multiple-definition (ODR) symbols
    for LED_BRIGHTNESS_*, COLON_BLINK_POSITIONS, GPS_*_PREFIX, message
    strings, TEXT_BUFFER_SIZE, WEEKDAY_NAMES, MONTH_NAMES. Also fix the
    GPS_SIGNAL_TIMEOUT_MS comment (says 60s, value is 30000ms).
    - main.cpp displayGpsLocation: wrap fractional parts in fabs() so that
    negative latitude/longitude/altitude format as "-12.3456" instead of
    "-12.-3456".
    - main.cpp scrollTextHorizontally: drain Serial inside the scroll loop
    and feed by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
    [config.h, main.cpp]
2026-05-17 Add Wokwi GPS simulator chip for full-stack simulation (#11)
    Previously the Wokwi diagram had only the Arduino Nano and MAX7219 matrix,
    so the firmware sat in the "no GPS signal" path forever (rain effect) when
    simulated. This adds a custom Wokwi chip that emulates a NEO-6M GPS module
    sending NMEA GPRMC/GPGGA sentences at 115200 baud, fixed at Bangalore
    (12.9716 N, 77.5946 E, 920m altitude) with a 5-second delay before first
    fix so the rain effect is still briefly visible at boot.
    - chips/gps-simulator.chip.c: chip source (no libc dependency; hand-rolled
    string helpers to keep the wasm small)
    - chips/gps-simulator.chip.json: chip metadata, pins TX/RX/VCC/GND
    - chips/gps-simulator.chip.was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
    [gps-simulator.chip.c]
2026-05-17 Replace 3D case with parametric OpenSCAD redesign (#12)
    The previous case files were one-off STLs with no source. This drops
    in a parametric OpenSCAD source so the case can be re-customized for
    different LED matrix sizes, screw spacings, ventilation options, etc.,
    and re-exported as needed.
    Replaces:
    - assets/display_ring.stl -> assets/ring.stl
    - assets/led_case.stl -> assets/case.stl
    - assets/led_case_back_panel.stl -> assets/back_panel.stl
    Adds:
    - assets/clock_case.scad: parametric source (OpenSCAD 2019.05+),
    toggle render flags in the Assembly section to export each piece.
    Includes NEO-6M GPS mounting, M3 screw mounts, rounded corners,
    optional cross-flow ventilati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
    [back_panel.stl, case.stl, clock_case.scad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]
2026-05-17 Add release workflow that publishes firmware on v* tags (#14)
    Pushing a tag matching v* (e.g. v1.0.0, v1.0.0-rc1) builds the firmware
    on PlatformIO and creates a GitHub Release with the .hex (flash image)
    and .elf (debugging) attached, named gps-led-clock-<tag>.{hex,elf}.
    Release body includes:
    - avrdude / Arduino IDE / xLoader flashing instructions
    - Note about disconnecting GPS TX from pin 0 before upload
    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
2026-08-25 fix(case): correct LED matrix pocket clearances to datasheet dimensions
    The pocket width was derived from 32 mm, the size of the matrix area
    alone, rather than the 33 mm module width given in the Handson
    Technology DSP-1172 datasheet. The intended 1 mm clearance was
    therefore consumed by the wrong base dimension and the pocket came out
    at exactly 33 mm, a press fit. Height had no clearance at all.
    Base dimensions now match the datasheet (128 x 33 x 15 mm) and the
    clearances are named parameters:
    pocket 129 x 34 x 15.5
    clear 1 x 1 x 0.5
    Pocket top moves from z=15.64 to z=16.14, leaving 12.36 mm of headroom
    under the back panel.
    [clock_case.scad]
2026-10-11 feat(hal): add board.h and move the GPS to software serial on pin 8 (#18)
    - New src/board.h: pins and board calls, with a block for the Nano
    (AVR) only. Other cores stop the build with #error until they get
    their own block.
    - GPS on NeoSWSerial, RX pin 8 and TX pin 9, at 9600 baud. D0 and D1
    stay free, so upload and the serial monitor work with the GPS
    wired. The GPS module must be set to 9600. A baud rate NeoSWSerial
    cannot do now stops the build.
    - waitMs() reads the GPS during every animation delay, so the 64 byte
    receive buffer does not overflow at 9600.
    - Max72xxPanel: SPI and pin setup moved from the constructor to
    begin(), a blank frame is sent before the display is swit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
2026-10-11 feat(logic): move hardware-free logic to lib/ClockLogic with PC tests (#19)
    - New lib/ClockLogic with no Arduino.h: time digits, ordinal suffix,
    date text, number format, trimmed mean and the power cycle counter.
    - main.cpp and GpsStabilityFilter use it. The three copies of the
    filter mean and the bubble sort are gone.
    - LAT, LON and ALT are now rounded, not cut off (12.9716, not
    12.9715), and a value between -1 and 0 keeps its minus sign.
    - The format avoids the "*" printf width, which avr-libc does not
    have.
    - [env:native] runs 10 Unity tests on the PC (pio test -e native).
    CI runs them after the Nano build.
    - The GPS filter window comment now says 30 minutes, not 12 seconds.
    Pa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
2026-10-11 feat(hal): add Wemos D1 mini and ESP32 board envs (#20)
    - src/board.h gets ESP8266 and ESP32 blocks with the same calls as
    the Nano: gpsSerial(), gpsBegin(), spiBegin(), storageBegin(),
    storageCommit() and seedRandom().
    - D1 mini: GPS on the core SoftwareSerial, D2 (GPIO4), receive only.
    ESP32 family: GPS on Serial1 with the RX pin from the env, matrix on
    the board's hardware SPI pins.
    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
